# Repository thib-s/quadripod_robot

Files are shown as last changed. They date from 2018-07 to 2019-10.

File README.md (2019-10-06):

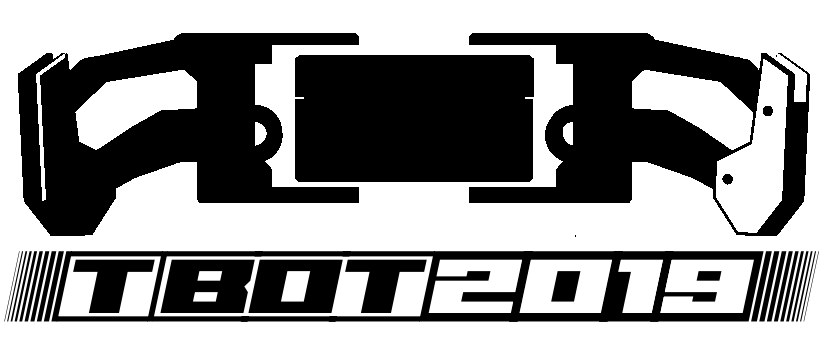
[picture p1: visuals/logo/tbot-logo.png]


Quadripod robot
===================

All the files to build a quadripod, including 3d model, eagle files and ROS code.

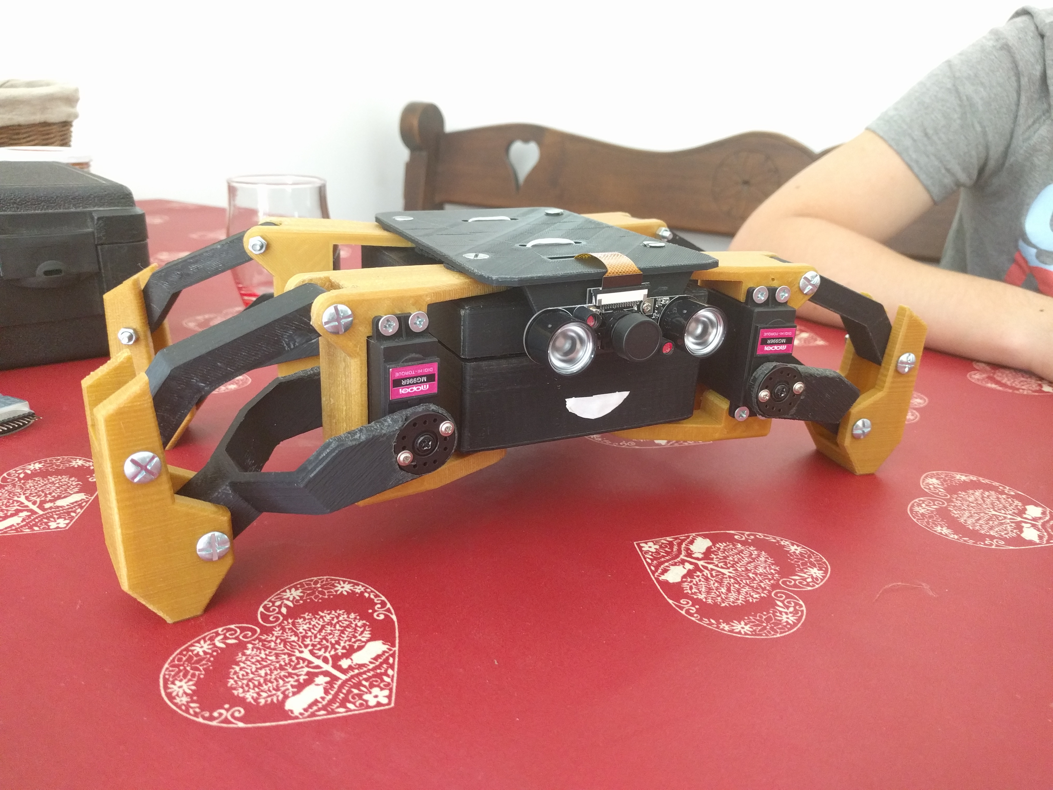
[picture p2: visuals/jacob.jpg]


Disclaimer
==========

This is a personal project, this means that this quadripod was build in a single exemplary. It worked fine for me, but i cannot be held responsible if you fry somehing using my plans.

Repository organization
=======================

3D
--

Contains stl for 3d print the robot, there are the original files from hackaday: [https://hackaday.io/project/9334-kame-esp8266-based-quadruped]. It contains also the modified STL to build the same base with mg996 servos.

Quadripod\_board
-------------

Contains the eagle files for the pcb manufacturing.

Code
----

Contains the code that runs on the raspberry pi zero:
 - The folder `catkin\_ws` contains the node to run locally on the robot. 
 - The folder `camera\_calibration` contains the files to calibrate the camera. 
 - The folder `teleop\_ws contains` the nodes to control the robot remotely using a joystick.
 
ROSpbianZero
------------

Contains the tutorial to setup the raspberry pi zero:
 1. install raspbian lite
 2. compile and install ros kinetic (perception)
 3. setup the service to start a launchfile at boot
 4. setup the wifi AP

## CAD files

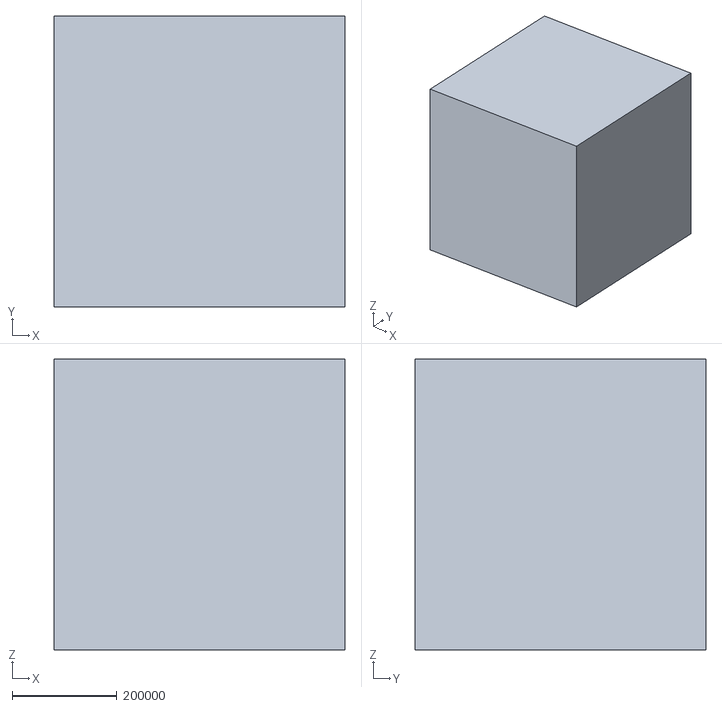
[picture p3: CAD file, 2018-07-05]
3d/mg996_base/exports/assembly.stl
554763.2 x 554763.2 x 554763.2

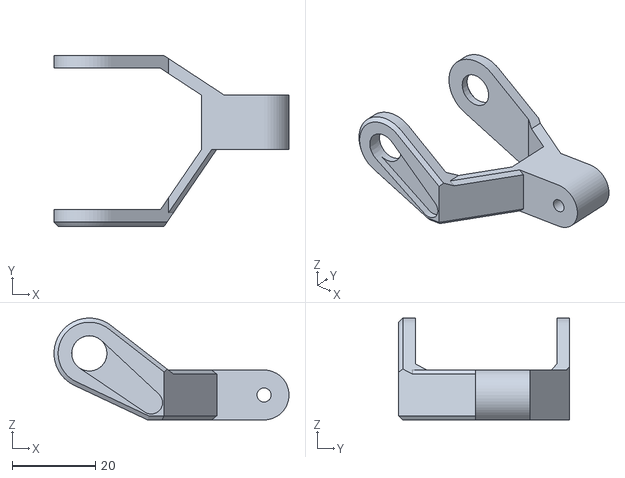
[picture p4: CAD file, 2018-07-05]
3d/hackaday_base/leftLegB.stl
56.5 x 41.0 x 24.5

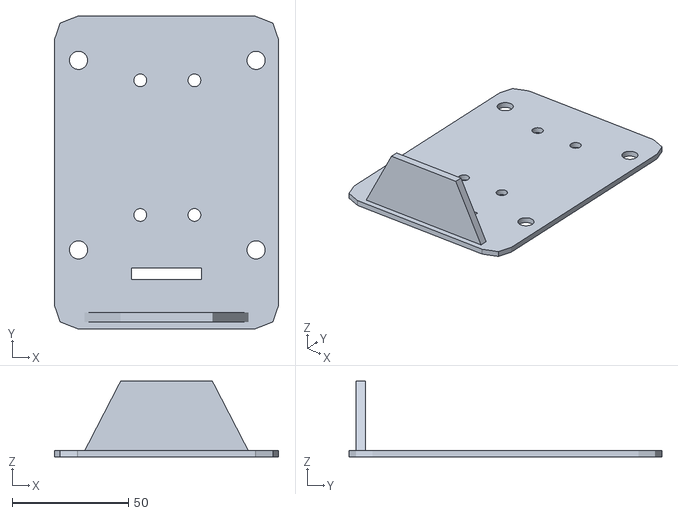
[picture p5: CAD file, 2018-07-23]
3d/mg996_base/exports/raspi_hat.stl
96.5 x 134.7 x 32.7

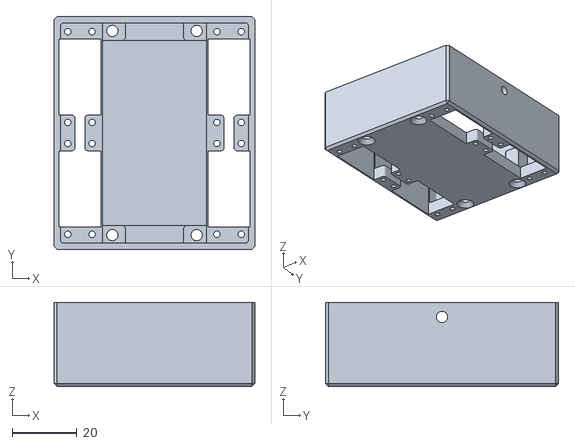
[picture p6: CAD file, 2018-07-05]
3d/hackaday_base/bodyB.stl
62.0 x 72.0 x 26.0

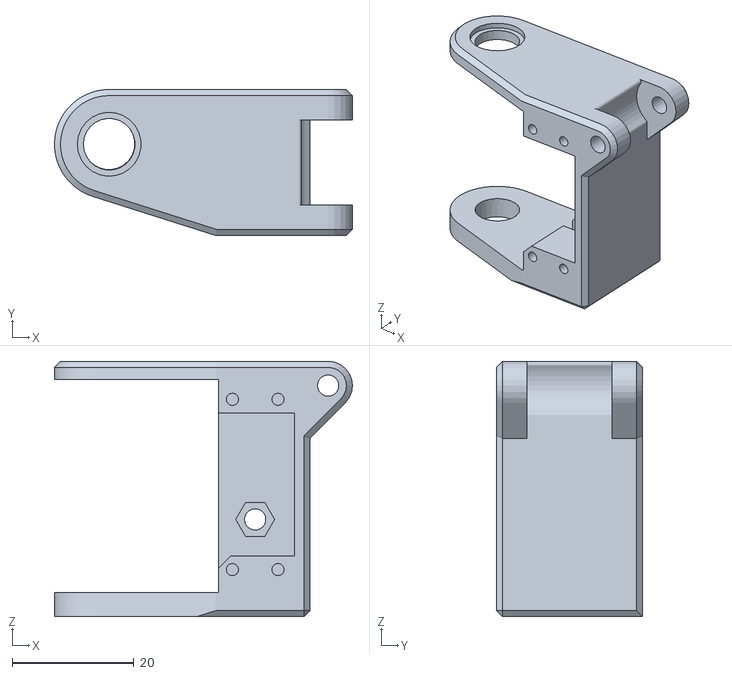
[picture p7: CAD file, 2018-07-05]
3d/mg996_base/leftBracket.stl
49.0 x 24.0 x 42.0

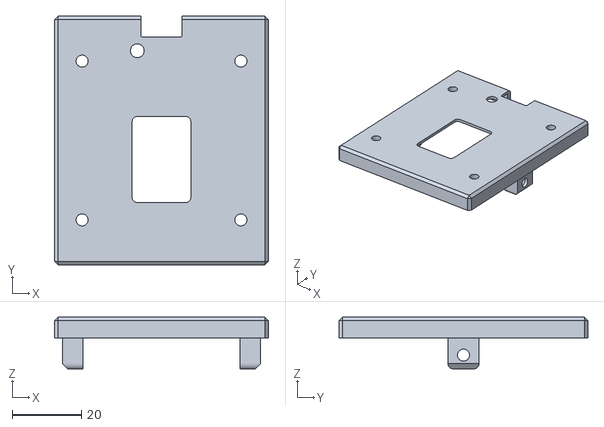
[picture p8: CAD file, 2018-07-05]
3d/mg996_base/bodyA.stl
62.0 x 72.0 x 15.0

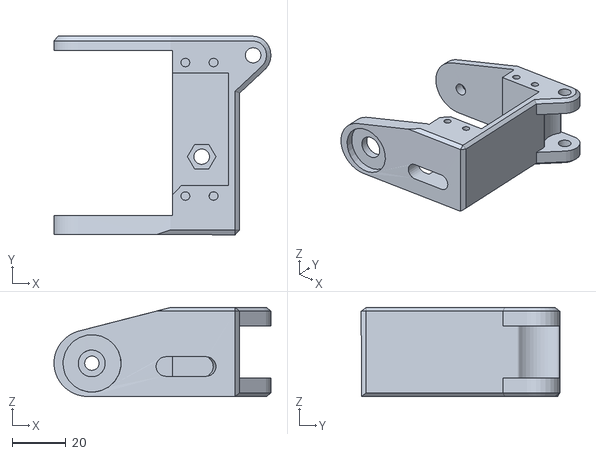
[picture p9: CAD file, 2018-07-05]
3d/mg996_base/exports/bracket.stl
80.6 x 73.7 x 33.0

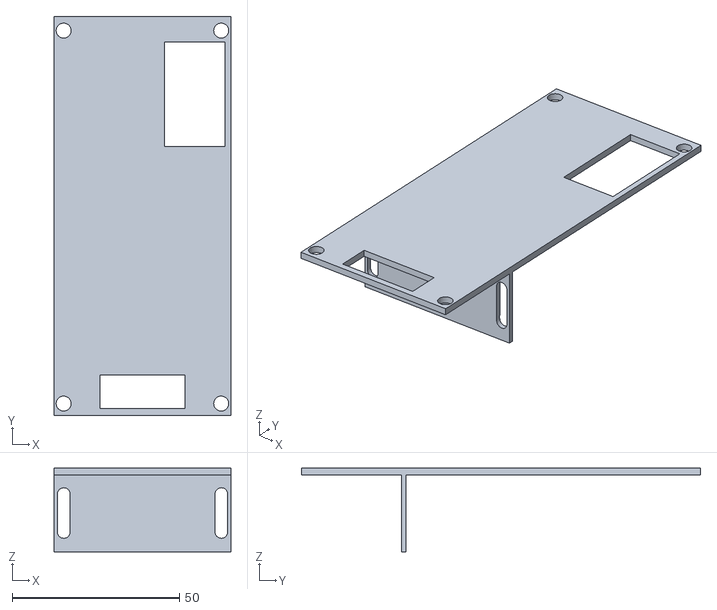
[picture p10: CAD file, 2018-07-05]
3d/mg996_base/exports/inner_body.stl
52.8 x 119.3 x 25.0

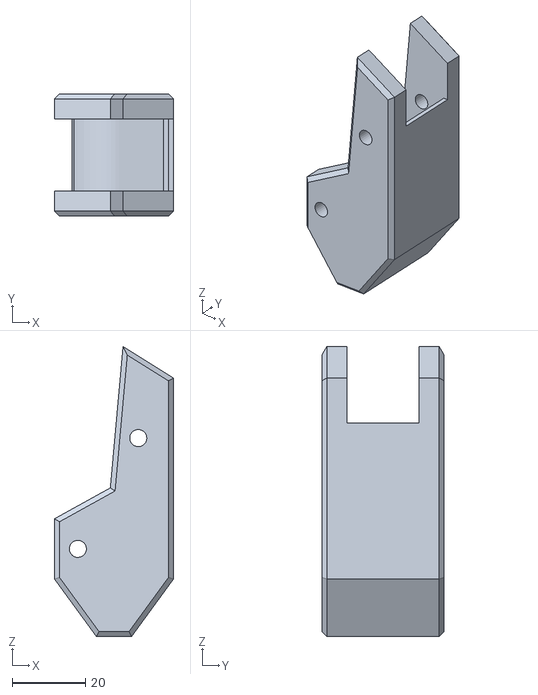
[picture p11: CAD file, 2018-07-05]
3d/mg996_base/exports/foot.stl
32.6 x 33.5 x 79.3

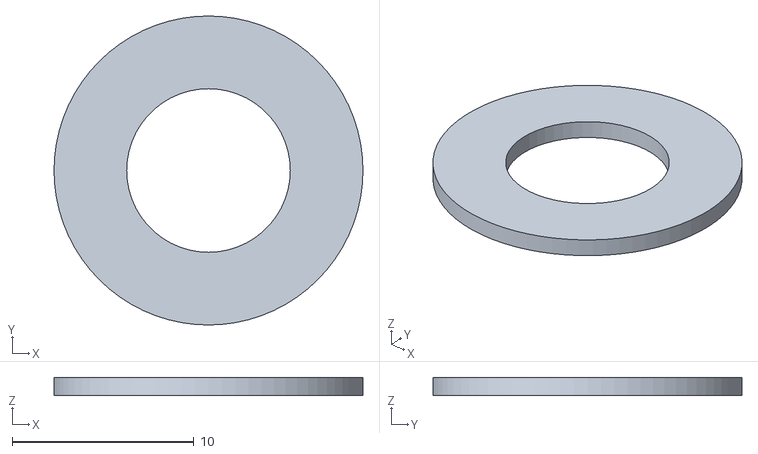
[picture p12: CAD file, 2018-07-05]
3d/hackaday_base/spacer.stl
17.0 x 17.0 x 1.00

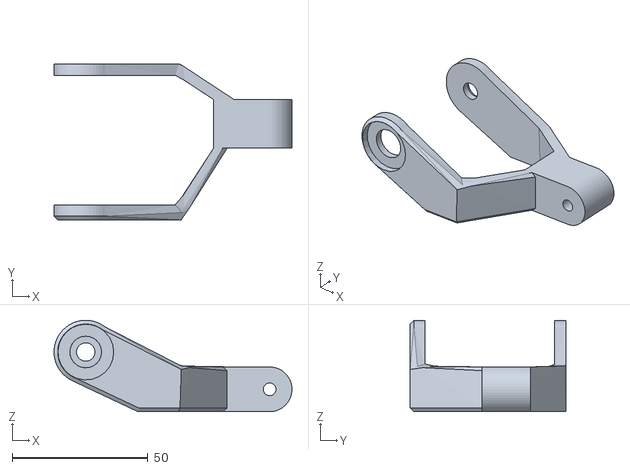
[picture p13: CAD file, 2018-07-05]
3d/mg996_base/exports/legB.stl
87.8 x 57.5 x 33.7

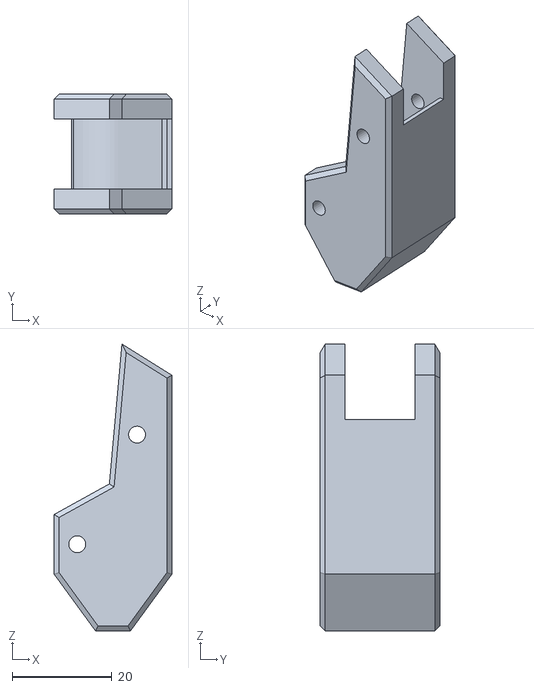
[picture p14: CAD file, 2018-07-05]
3d/hackaday_base/foot.stl
23.6 x 24.0 x 57.6

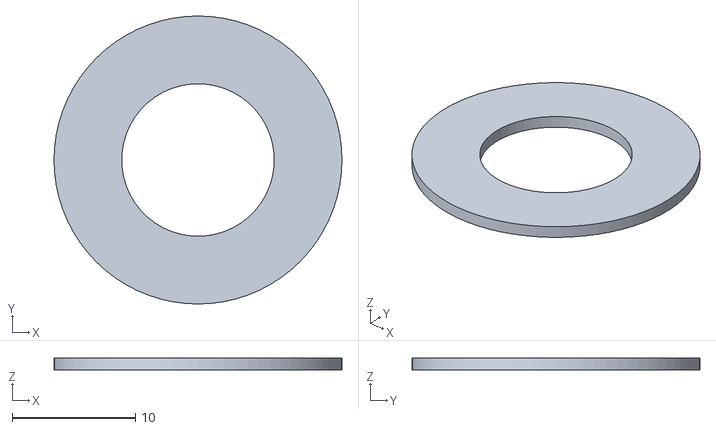
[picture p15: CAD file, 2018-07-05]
3d/mg996_base/exports/spacer.stl
23.4 x 23.4 x 1.00

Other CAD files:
3d/hackaday_base/rightBracket.stl
3d/hackaday_base/rightLegB.stl
3d/hackaday_base/legA.stl
3d/mg996_base/assembly.blend
3d/mg996_base/bodyA.blend
3d/mg996_base/bodyB.blend
3d/mg996_base/bracket.blend
3d/mg996_base/exports/bodyA.stl
3d/mg996_base/exports/bodyB.stl
3d/mg996_base/exports/legA.stl
3d/mg996_base/foot.blend
3d/mg996_base/inner_body.blend
3d/mg996_base/legA.blend
3d/mg996_base/legA.stl
3d/mg996_base/legB.blend
3d/mg996_base/raspi_hat.blend
3d/mg996_base/spacer.blend

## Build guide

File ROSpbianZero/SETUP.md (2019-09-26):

ROSpbianZero
============

This is a distribution is a modified RaspbianLite iso with ROS kinetic installed. This iso can also be configured to use the raspberry pi zero as a wifi hotspot.

The setup is split as follow:

1. raspbian stretch install
2. increase swap
3. ros compilation and install
4. wifi setup
5. setup to run nodes at boot
6. iso packing for further use

1: raspbian stretch install:
----------------------------

Go the [Raspbian website](https://www.raspberrypi.org/downloads/raspbian/) and download the the *Raspbian Lite* iso. Choose *raspbian jessie*.

Once done install it on a 16Go micro sd  ([tutorial](https://tutorials.ubuntu.com/tutorial/tutorial-create-a-usb-stick-on-ubuntu#0))

Log into the raspberry pi:
  login:pi
  pass:raspberry

change password and launch:
```
# sudo raspi-config
```
choose *expand filesystem*. You can also choose to enable ssh service (recommended). Enable camera and reboot.

Now install pigpio (usefull if you need the gpio! ):
```
# sudo apt-get update
# sudo apt-get install pigpio python-pigpio python3-pigpio
```

2: increase swap:
-----------------

Follow the [tutorial](https://wpitchoune.net/tricks/raspberry_pi3_increase_swap_size.html) and increase swap to 1024mb.

3: ROS install:
---------------

Add the repositories [step 1.2 - 1.3 of this tutorial](http://wiki.ros.org/kinetic/Installation/Ubuntu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)

Now follow the [tutorial](http://wiki.ros.org/kinetic/Installation/Source) to install ros kinetic from sources. **ATTENTION!!** read the entire paragraph before doing the tutorial, as some changes apply:

**edit 1**
in step 2.1.1 don't choose *desktop install* as we don't have any GUI. Choose *perception* instead. See also the [list of available variants](http://www.ros.org/reps/rep-0131.html#variants)
```
$ rosinstall\_generator robot perception --rosdistro kinetic --deps --wet-only --tar > kinetic-robot-perception-wet.rosinstall
$ wstool init -j8 src kinetic-robot-perception -wet.rosinstall
```

**edit 2**
Some package won't compile as is, you must apply the following patch:

```
-find_package(Eigen3 REQUIRED)
+find_package(PkgConfig)
+pkg_search_module(Eigen3 REQUIRED eigen3)
```  

Take a nap, the compile time is veeeeeerry long. You may also want to use *screen* or *byobu* to disconnet you ssh connection without stopping the compilation.

**Note:** Once the install is done and working you can delete the compilation folder. This will allow you to free up to 2Gb. (Usefull especially when packing the final iso).

4: wifi setup:
--------------

Follow [this tutorial](https://www.raspberrypi.org/documentation/configuration/wireless/access-point.md). The part *Using the Raspberry Pi as an access point to share an internet connection (bridge)* is optionnal.

5: setup ROS node at boot:
--------------------------

Create the file `/etc/systemd/system/bringup.service`:
```
[Unit]
Restart=on-abort
Description=ros\_bringup
After=network.target
  
[Service]
ExecStart=/bin/bash /usr/local/bin/bringup.sh

[Install]
WantedBy=default.target
```
This file will allow run `/usr/local/bin/bringup.sh` at boot.

Create now `/usr/local/bin/bringup.sh`:
```
#!/usr/bin/env bash
bash -c "source /opt/ros/kinetic/setup.bash && source /home/pi/catkin\_ws/devel/setup.bash && export ROS\_HOSTNAME=192.168.4.1 && export ROS\_MASTER\_URI=http://192.168.4.1:11311 && roslaunch bringup\_package bringup.launch > /tmp/bringup.log"
```

This command line allow to:
 - source ros executable
 - source your workspace executables
 - export variables to allow remote  ROS hosts
 - launch a launchfile

You may want to change this in order to launch an other launchfile. Without modifications this file run `bringup.launch` in the `bringup_package`.

Now adjust the acces:
```
# chmod 744 /usr/local/bin/bringup.sh
```

Then enable the service:
```
# chmod 664 /etc/systemd/system/bringup.service
# systemctl daemon-reload
# systemctl enable bringup.service
Created symlink from /etc/systemd/system/default.target.wants/bringup.service to /etc/systemd/system/bringup.service.
```

And start the service:
```
systemctl start bringup.service
```

**Note 1:** you can check the service status using `systemctl status bringup.service`

**Note 2:** The console output will be redirected in `/tmp/bringup.log`, this file is deleted at each restart.

6: pack the iso file:
---------------------

 1. poweroff the raspberry pi
 2. connect the sd card to a linux computer (ubuntu used to make this tutorial)
 3. run the `Disks` app
 4. select your sd card
 5. go into the options (top right button) and choose *create disk image*. Choose an iso name.

The obtained file is the size of the card (16Go), you can shrink it to it's minimal size (4.5Go) using [this tutorial](https://softwarebakery.com/shrinking-images-on-linux).

7: you're done!
---------------

This tutorial is intended for the raspberry pi zero, but also works on other models.

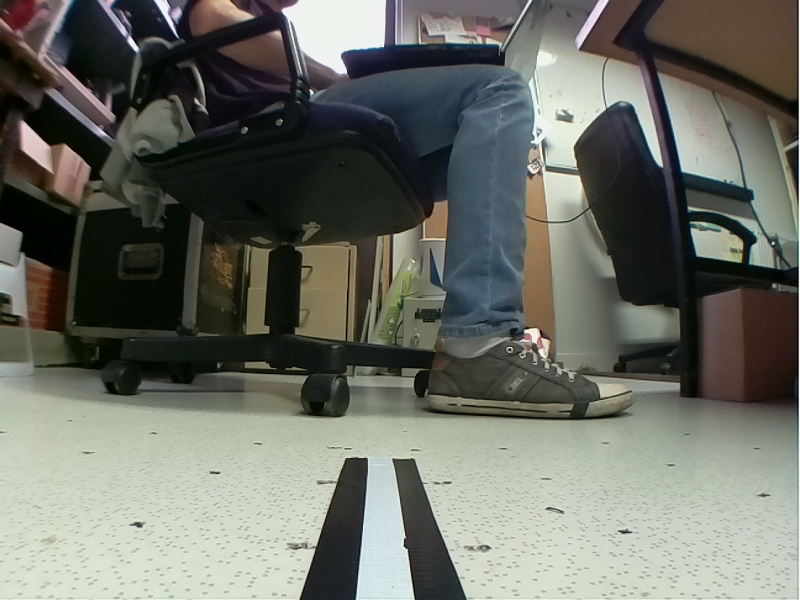
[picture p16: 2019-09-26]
code/camera_calibration/1step.png

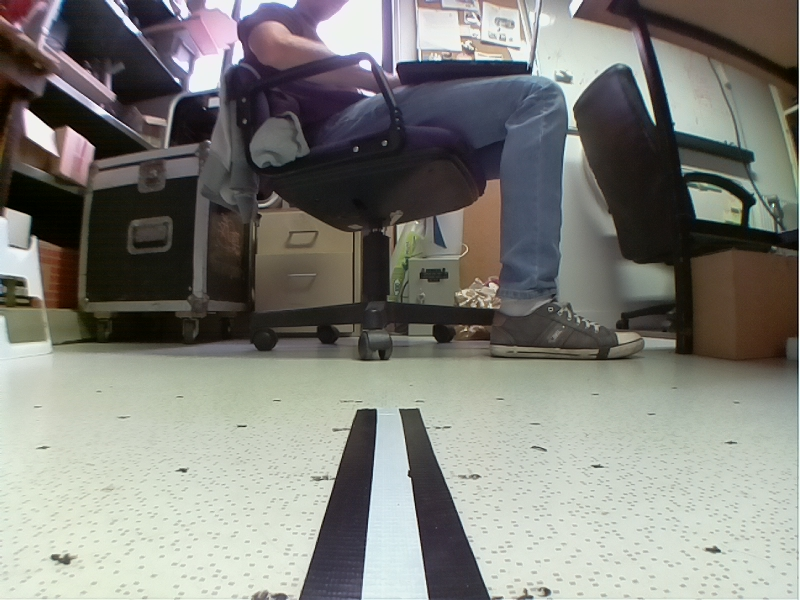
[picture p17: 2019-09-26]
code/camera_calibration/0step.png

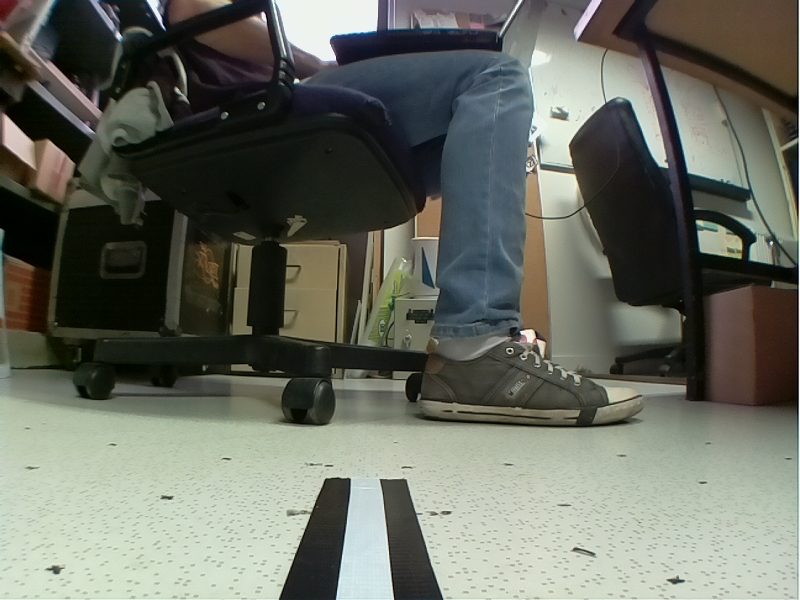
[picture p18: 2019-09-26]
code/camera_calibration/2step.png

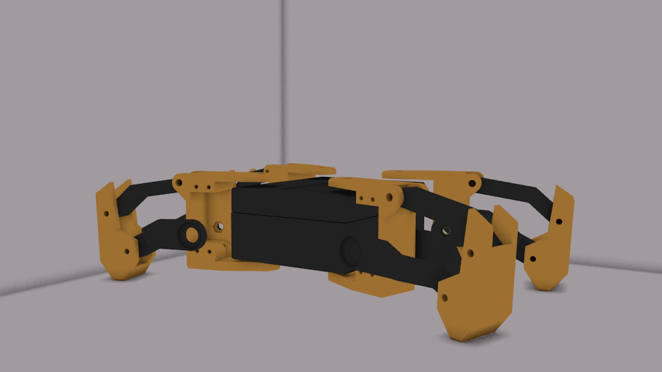
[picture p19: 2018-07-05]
3d/mg996_base/exports/assembly.png

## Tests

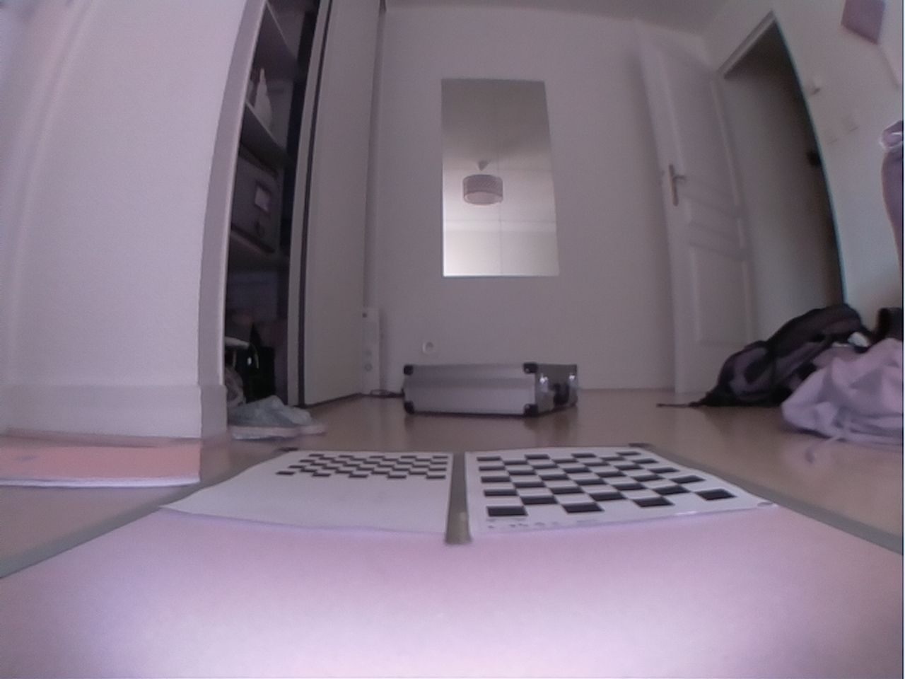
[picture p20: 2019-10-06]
code/camera_calibration/std.png

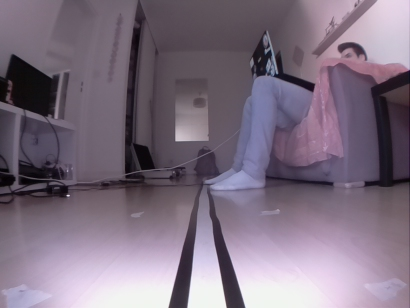
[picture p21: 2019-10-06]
code/camera_calibration/std_lowres.png

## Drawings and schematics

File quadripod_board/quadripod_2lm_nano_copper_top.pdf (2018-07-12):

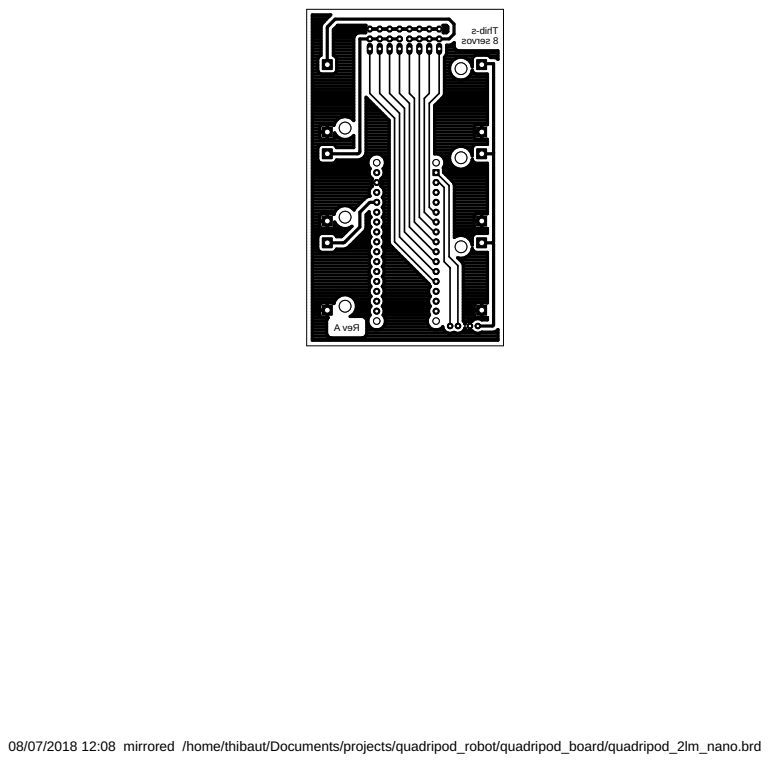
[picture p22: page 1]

08/07/2018 12:08 mirrored /home/thibaut/Documents/projects/quadripod_robot/quadripod_board/quadripod_2lm_nano.brd

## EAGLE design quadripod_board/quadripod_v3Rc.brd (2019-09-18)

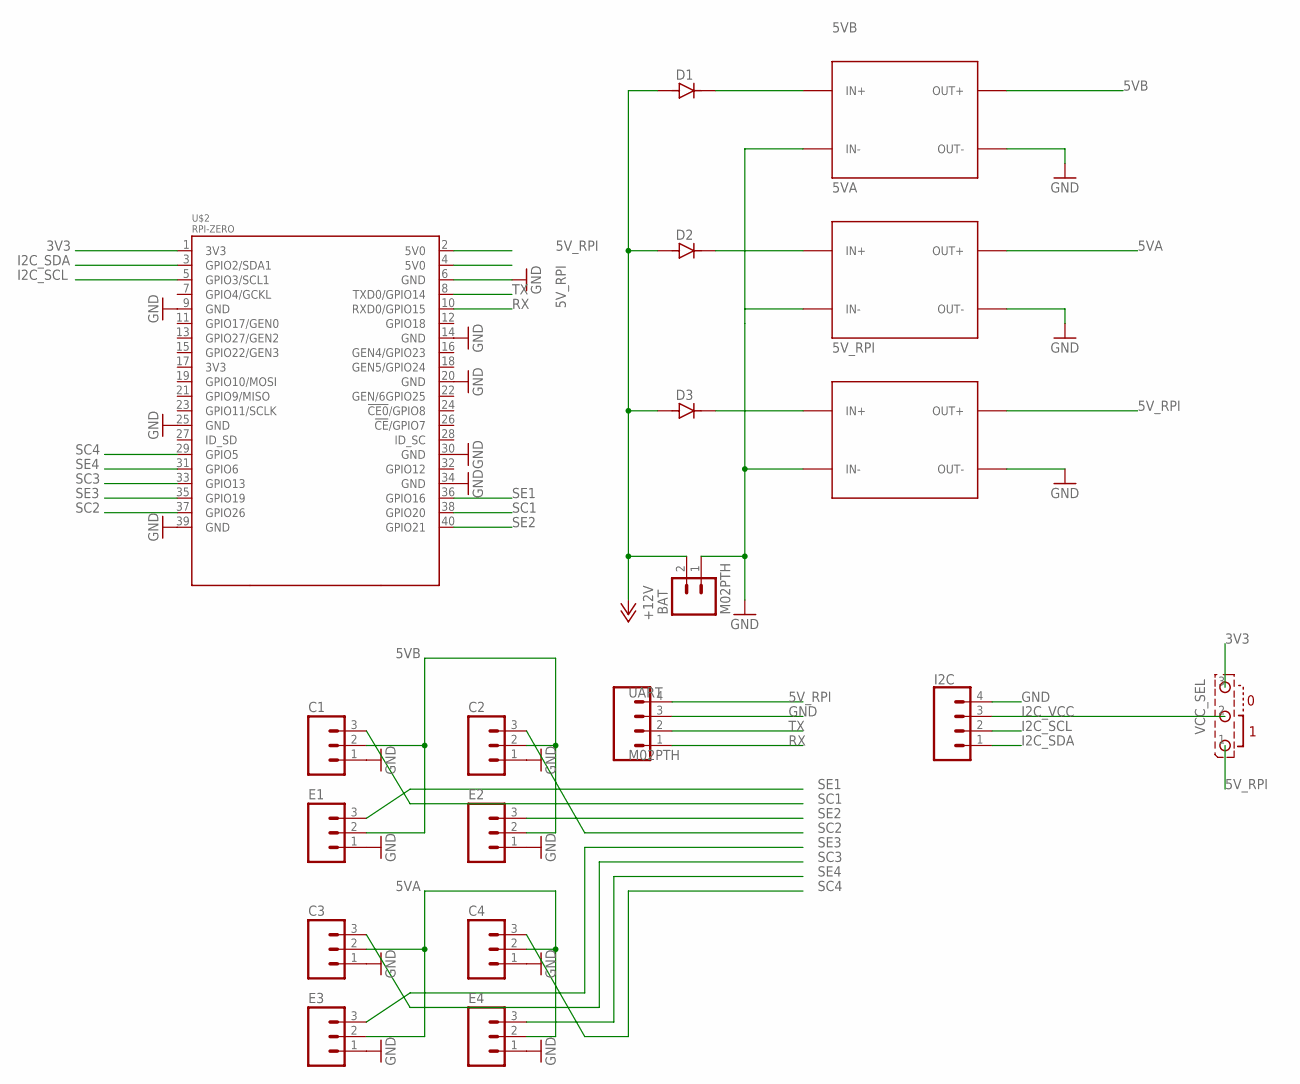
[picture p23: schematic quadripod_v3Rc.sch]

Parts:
5VA, 5VB, 5V_RPI: DC-DC-STEP-DOWN-LM2596
BAT: M02PTH; 1X02_LONGPADS
C1, C2, C3, C4: M03LONGPADS; 1X03_LONGPADS
D1, D2, D3: DIODES_DIODE/DO41; DIODES_DO41
E1, E2, E3, E4: M03LONGPADS; 1X03_LONGPADS
I2C: CONN_04LONGPADS; 1X04_LONGPADS
U$2: RPI-ZERO; RASPBERRYPI_BASTELSTUBE_V13_RASPI_BOARD_B+_FULL
UART: M02PTH; 1X04_LONGPADS
VCC_SEL: STCMS_3/CMS; STCMS_3

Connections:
3V3: U$2.1 (3V3), VCC_SEL.3
5VA: 5VA.OUT+, C3.2, C4.2, E3.2, E4.2
5VB: 5VB.OUT+, C1.2, C2.2, E1.2, E2.2
5V_RPI: 5V_RPI.OUT+, U$2.2 (5V0), U$2.4 (5V0), UART.4, VCC_SEL.1
+12V: BAT.2, D1.A, D2.A, D3.A
GND: 5VA.IN-, 5VA.OUT-, 5VB.IN-, 5VB.OUT-, 5V_RPI.IN-, 5V_RPI.OUT-, BAT.1, C1.1, C2.1, C3.1, C4.1, E1.1, E2.1, E3.1, E4.1, I2C.4, U$2.6 (GND), U$2.9 (GND), U$2.14 (GND), U$2.20 (GND), U$2.25 (GND), U$2.30 (GND), U$2.34 (GND), U$2.39 (GND), UART.3
I2C_SCL: I2C.2, U$2.5 (GPIO3/SCL1)
I2C_SDA: I2C.1, U$2.3 (GPIO2/SDA1)
I2C_VCC: I2C.3, VCC_SEL.2
unnamed: 5VB.IN+, D1.K
unnamed: 5V_RPI.IN+, D3.K
unnamed: 5VA.IN+, D2.K
RX: U$2.10 (RXD0/GPIO15), UART.1
SC1: C1.3, U$2.38 (GPIO20)
SC2: C2.3, U$2.37 (GPIO26)
SC3: C3.3, U$2.33 (GPIO13)
SC4: C4.3, U$2.29 (GPIO5)
SE1: E1.3, U$2.36 (GPIO16)
SE2: E2.3, U$2.40 (GPIO21)
SE3: E3.3, U$2.35 (GPIO19)
SE4: E4.3, U$2.31 (GPIO6)
TX: U$2.8 (TXD0/GPIO14), UART.2

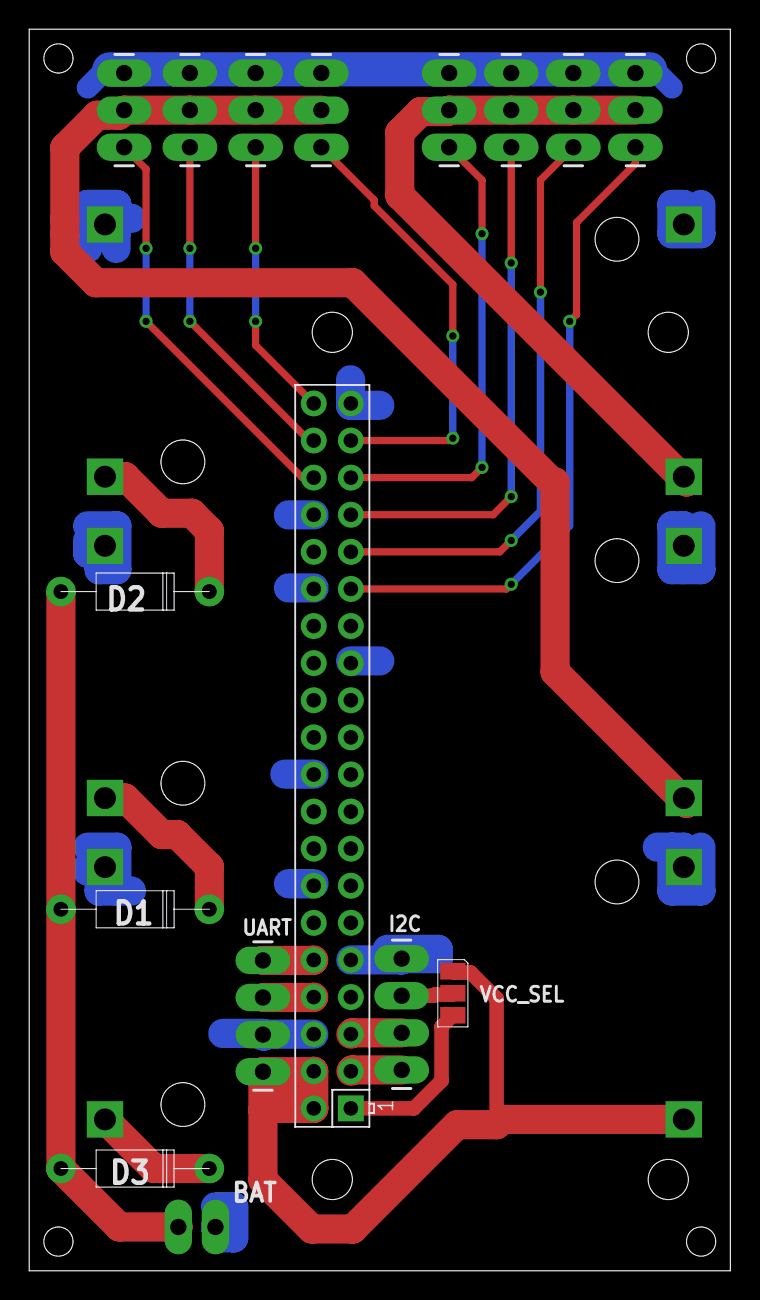
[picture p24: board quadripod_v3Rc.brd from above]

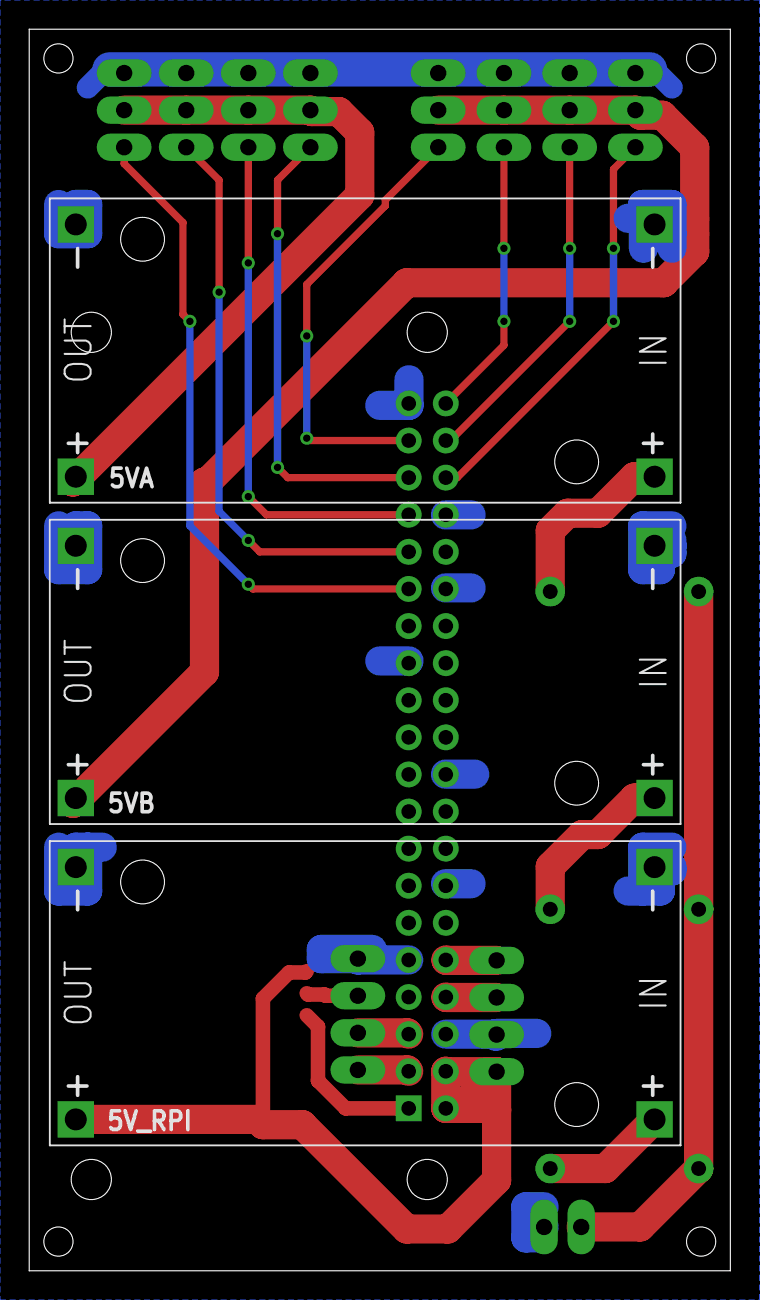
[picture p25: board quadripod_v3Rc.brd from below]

Board: 2 copper layers, 48.0 x 85.0 mm, 19 parts (4 on the bottom side), 22 nets.

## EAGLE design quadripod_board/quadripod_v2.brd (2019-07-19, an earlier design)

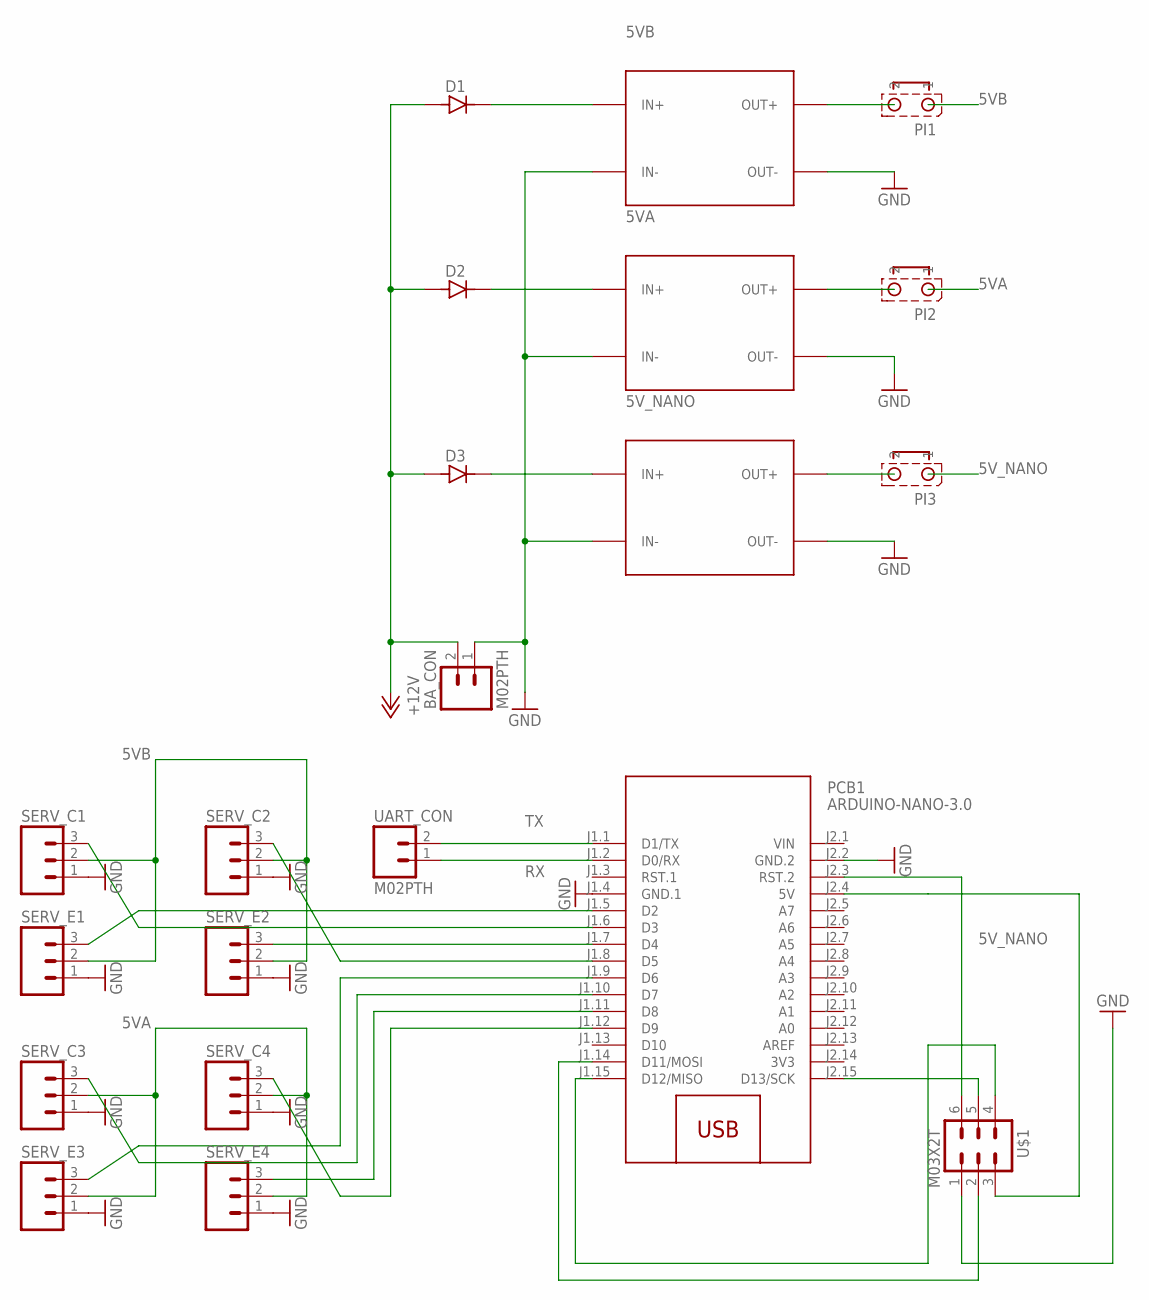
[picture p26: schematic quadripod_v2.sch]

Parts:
5VA, 5VB, 5V_NANO: DC-DC-STEP-DOWN-LM2596
BA_CON: M02PTH; 1X02
D1, D2, D3: DIODES_DIODE/DO41; DIODES_DO41
PCB1: ARDUINO-NANO-3.0
PI1, PI2, PI3: STCMS_2
SERV_C1, SERV_C2, SERV_C3, SERV_C4: M03LONGPADS; 1X03_LONGPADS
SERV_E1, SERV_E2, SERV_E3, SERV_E4: M03LONGPADS; 1X03_LONGPADS
U$1: M03X2T; 2X03
UART_CON: M02PTH; 1X02

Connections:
3V3: PCB1.J2.14 (3V3)
5VA: PI2.1, SERV_C3.2, SERV_C4.2, SERV_E3.2, SERV_E4.2
5VB: PI1.1, SERV_C1.2, SERV_C2.2, SERV_E1.2, SERV_E2.2
5V_NANO: PCB1.J2.4 (5V), PI3.1, U$1.3
+12V: BA_CON.2, D1.A, D2.A, D3.A
GND: 5VA.IN-, 5VA.OUT-, 5VB.IN-, 5VB.OUT-, 5V_NANO.IN-, 5V_NANO.OUT-, BA_CON.1, PCB1.J1.4 (GND.1), PCB1.J2.2 (GND.2), SERV_C1.1, SERV_C2.1, SERV_C3.1, SERV_C4.1, SERV_E1.1, SERV_E2.1, SERV_E3.1, SERV_E4.1, U$1.1
unnamed: 5VB.IN+, D1.K
unnamed: PCB1.J1.5 (D2), SERV_E1.3
unnamed: 5VA.IN+, D2.K
unnamed: 5V_NANO.IN+, D3.K
unnamed: PCB1.J1.6 (D3), SERV_C1.3
unnamed: PCB1.J1.7 (D4), SERV_E2.3
unnamed: PCB1.J1.8 (D5), SERV_C2.3
unnamed: PCB1.J1.9 (D6), SERV_E3.3
unnamed: PCB1.J1.10 (D7), SERV_C3.3
unnamed: PCB1.J1.11 (D8), SERV_E4.3
unnamed: PCB1.J1.12 (D9), SERV_C4.3
unnamed: 5VB.OUT+, PI1.2
unnamed: 5VA.OUT+, PI2.2
unnamed: 5V_NANO.OUT+, PI3.2
unnamed: PCB1.J1.14 (D11/MOSI), U$1.2
unnamed: PCB1.J2.3 (RST.2), U$1.6
unnamed: PCB1.J2.15 (D13/SCK), U$1.5
unnamed: PCB1.J1.15 (D12/MISO), U$1.4
RX: PCB1.J1.2 (D0/RX), UART_CON.1
TX: PCB1.J1.1 (D1/TX), UART_CON.2
VIN: PCB1.J2.1 (VIN)

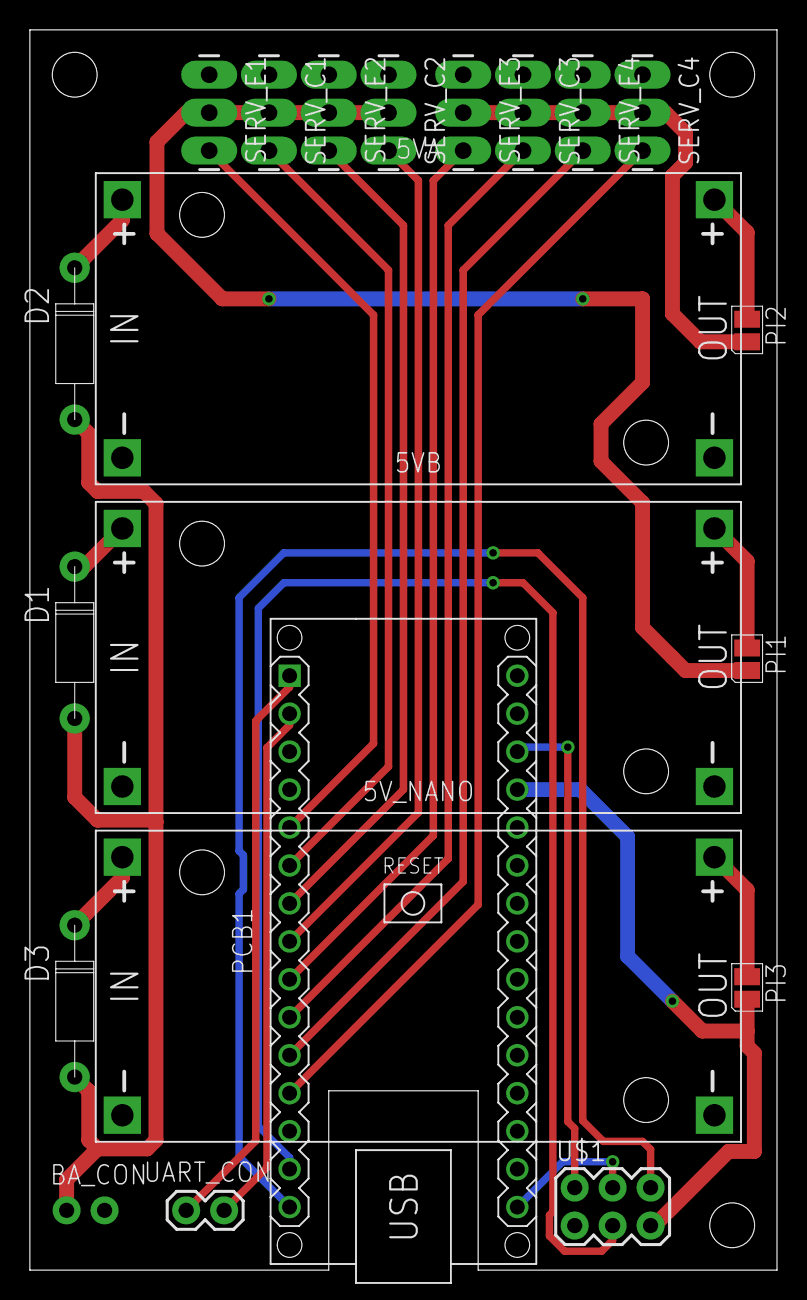
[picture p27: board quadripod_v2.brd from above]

Board: 2 copper layers, 50.0 x 83.0 mm, 21 parts (1 on the bottom side), 25 nets.

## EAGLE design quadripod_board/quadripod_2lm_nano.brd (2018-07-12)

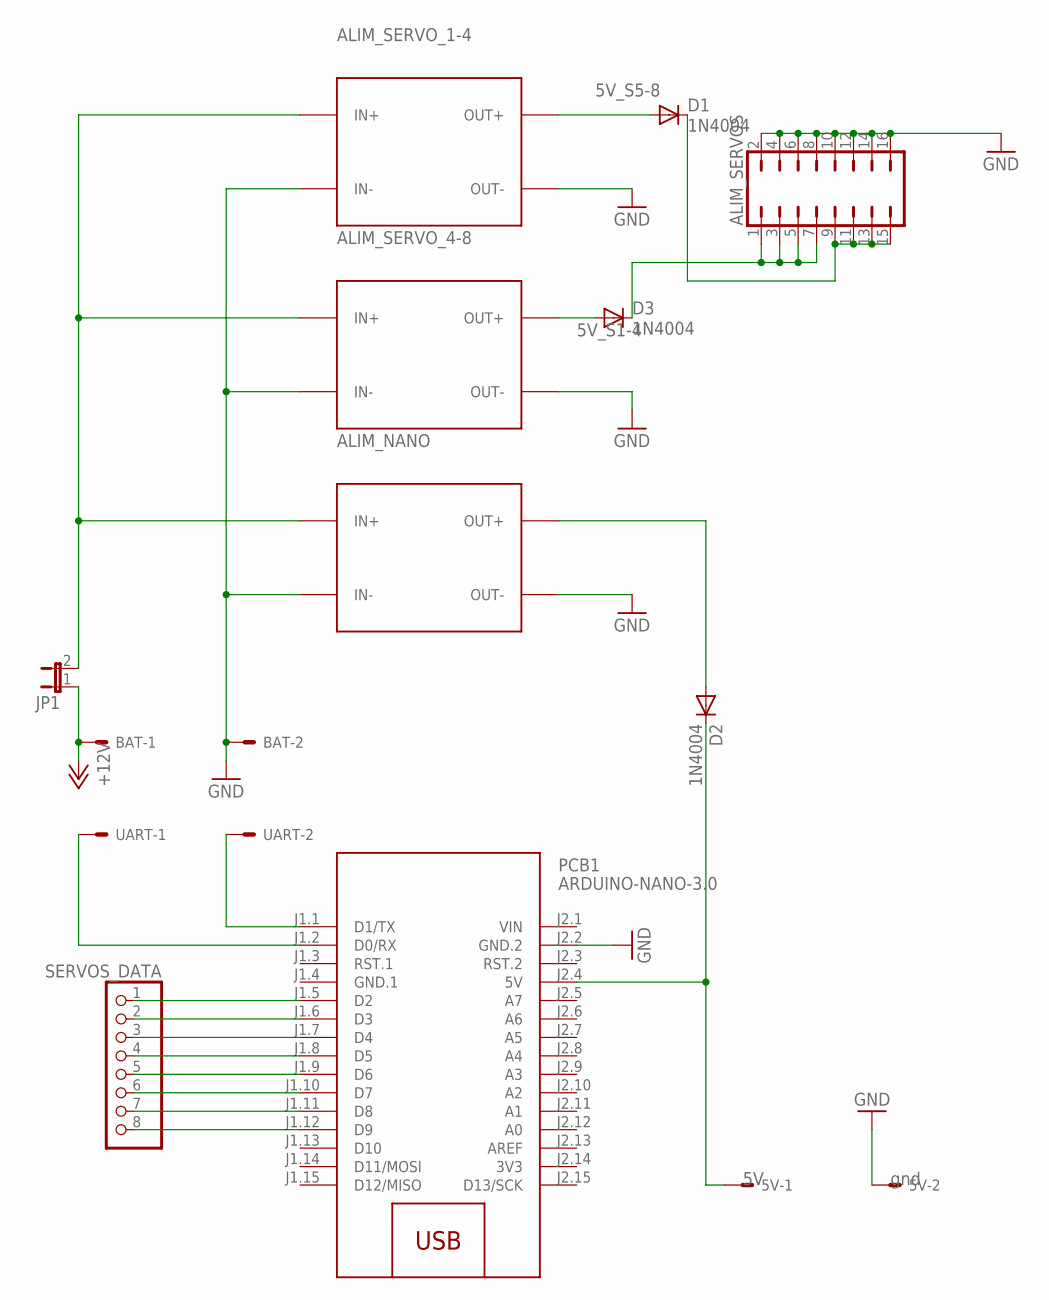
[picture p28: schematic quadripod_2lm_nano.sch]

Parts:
5V: 332-02
ALIM_NANO: DC-DC-STEP-DOWN-LM2596
ALIM_SERVOS: JP8Q
ALIM_SERVO_1-4, ALIM_SERVO_4-8: DC-DC-STEP-DOWN-LM2596
BAT: 332-02; VOLTAGE 12V
D1, D2, D3: 1N4004; DO41-10
JP1: JP1E; JP1
PCB1: ARDUINO-NANO-3.0
SERVOS_DATA: PINHD-1X8; 1X08
UART: 332-02

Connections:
3V3: PCB1.J2.14 (3V3)
5V_NANO: ALIM_NANO.OUT+, D2.A
5V_S1-4: ALIM_SERVOS.1, ALIM_SERVOS.3, ALIM_SERVOS.5, ALIM_SERVOS.7, D3.C
5V_S5-8: ALIM_SERVOS.9, ALIM_SERVOS.11, ALIM_SERVOS.13, ALIM_SERVOS.15, D1.C
+12V: BAT.1, JP1.1
GND: 5V.2, ALIM_NANO.IN-, ALIM_NANO.OUT-, ALIM_SERVOS.2, ALIM_SERVOS.4, ALIM_SERVOS.6, ALIM_SERVOS.8, ALIM_SERVOS.10, ALIM_SERVOS.12, ALIM_SERVOS.14, ALIM_SERVOS.16, ALIM_SERVO_1-4.IN-, ALIM_SERVO_1-4.OUT-, ALIM_SERVO_4-8.IN-, ALIM_SERVO_4-8.OUT-, BAT.2, PCB1.J2.2 (GND.2)
GND.1: PCB1.J1.4 (GND.1)
unnamed: ALIM_SERVO_4-8.OUT+, D3.A
unnamed: PCB1.J1.5 (D2), SERVOS_DATA.1
unnamed: 5V.1, D2.C, PCB1.J2.4 (5V)
unnamed: ALIM_SERVO_1-4.OUT+, D1.A
unnamed: PCB1.J1.6 (D3), SERVOS_DATA.2
unnamed: PCB1.J1.7 (D4), SERVOS_DATA.3
unnamed: PCB1.J1.8 (D5), SERVOS_DATA.4
unnamed: PCB1.J1.9 (D6), SERVOS_DATA.5
unnamed: PCB1.J1.10 (D7), SERVOS_DATA.6
unnamed: PCB1.J1.11 (D8), SERVOS_DATA.7
unnamed: PCB1.J1.12 (D9), SERVOS_DATA.8
unnamed: PCB1.J1.2 (D0/RX), UART.1
unnamed: PCB1.J1.1 (D1/TX), UART.2
unnamed: ALIM_NANO.IN+, ALIM_SERVO_1-4.IN+, ALIM_SERVO_4-8.IN+, JP1.2
VIN: PCB1.J2.1 (VIN)

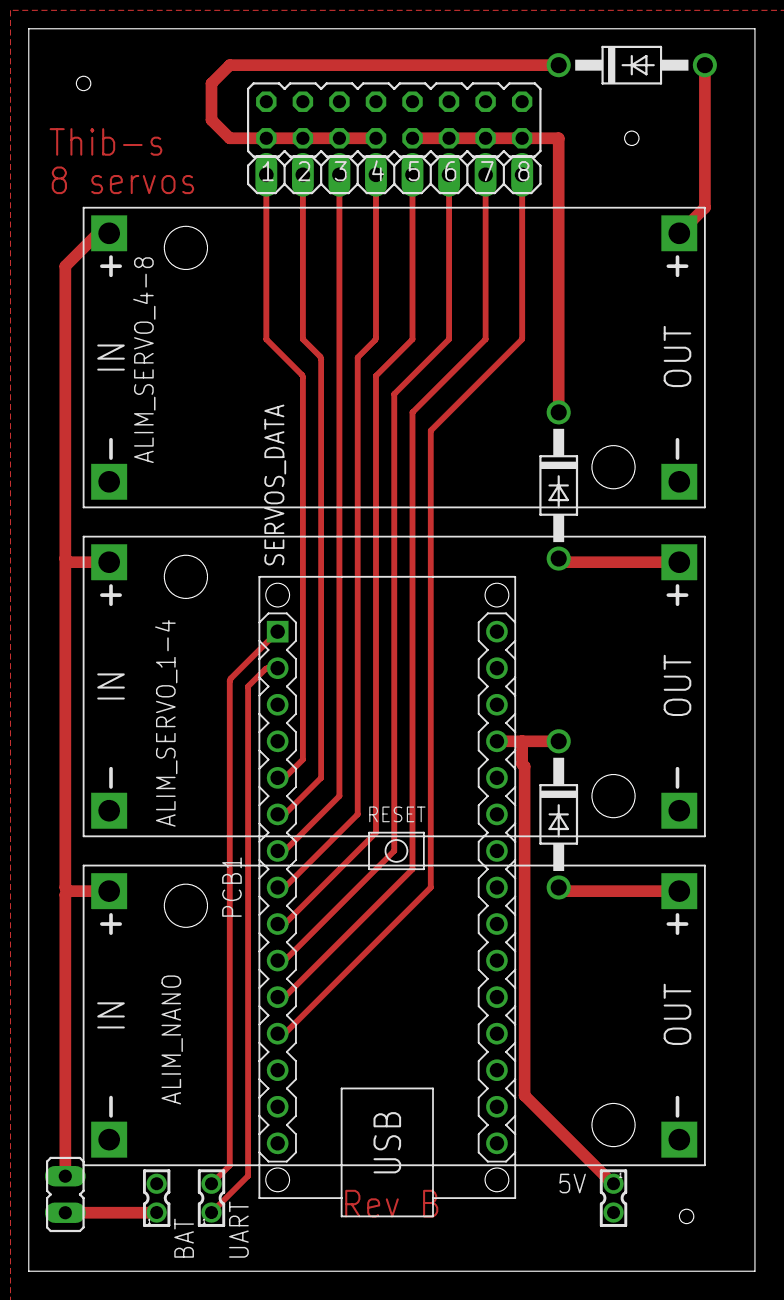
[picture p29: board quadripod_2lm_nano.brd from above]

Board: 2 copper layers, 50.5 x 86.4 mm, 13 parts (0 on the bottom side), 19 nets.

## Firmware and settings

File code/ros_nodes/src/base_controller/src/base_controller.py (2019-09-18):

#!/usr/bin/env python

# pulse.py

import rospy
from geometry_msgs.msg import Twist
import time
import numpy as np
import pigpio

deg2ms = lambda angle: (angle / 180.0) * 1000.0 + 1000.0


class ServoController():

    def __init__(self, pins=None):
        """
        Initialize the servo and move them to the standby position
        :return: nothing
        """
        if pins is None:
            # pins = [16, 20, 21, 26, 19, 13, 6, 5]
            # pins = [21, 26, 16, 20,6, 5, 19, 13]
            pins = [6,5,19,13,21,26,16,20]
        # gpio ids of each servo
        self.pins = pins

        self.pi = pigpio.pi()  # Connect to local Pi.

        # set gpio modes
        for pin in self.pins:
            self.pi.set_mode(pin, pigpio.OUTPUT)
        # start 1500 us servo pulses on gpio4
        for pin in self.pins:
            self.pi.set_servo_pulsewidth(pin, 1500)
            time.sleep(0.25)

    def move(self, position_sequence, correction, delay_step=0.25, delay_serv=0.0):
        for step in position_sequence:
            for i, pin in enumerate(self.pins):
                self.pi.set_servo_pulsewidth(pin, deg2ms(step[i] + correction[i]))
                time.sleep(delay_serv)
            time.sleep(delay_step)

    def release(self):
        """
        release all servos and stop the deamon
        :return:
        """
        for pin in self.pins:
            self.pi.set_servo_pulsewidth(pin, 0)  # stop servo pulses
        self.pi.stop()  # terminate connection and release resources


class QuadripodModel():

    def __init__(self,):

        ################################################
        # static params of the gait
        ################################################

        # how much to raise the legs when walking
        self.delta = 20

        self.init_angles = np.array(
            [[90, 90 + self.delta, 90, 90 - self.delta, 90, 90 - self.delta, 90, 90 + self.delta]])
        # values to correct mechanical alignment of servos
        self.corrections = np.array([-20, 10, 20, 0, 20, 20, -20, 0])

        # how to affect the values when moving the body without walking
        # body_p* refers to position
        # body_o* refers to orientation
        self.body_pz = np.array([0, 1, 0, -1, 0, -1, 0, 1])
        self.body_px = np.array([-1, 0, 1, 0, -1, 0, 1, 0])
        self.body_py = np.array([0, 0, 0, 0, 0, 0, 0, 0])  # None
        self.body_ox = np.array([0, -1, 0, -1, 0, 1, 0, 1])  # untested
        self.body_oy = np.array([0, 1, 0, -1, 0, 1, 0, -1])
        self.body_oz = np.array([0, 0, 0, 0, 0, 0, 0, 0])  # None

        self.body_twist = Twist()
        self.body_twist.linear.x = 0.
        self.body_twist.linear.y = 0.
        self.body_twist.linear.z = 0.
        self.body_twist.angular.x = 0.
        self.body_twist.angular.y = 0.
        self.body_twist.angular.z = 0.

    ################################################
    # functions that compute movement of the robot
    ################################################

    def walk(self, twist):
        """
        compute the legs position sequence in order to perform the walk
        :param twist: the twist msg with the movement infos: twist.linear.y for translation, and twist.angular.z for
        rotation
        :return: the sequence of the servos position as np array
        """
        linear = 0.5 * twist.linear.y + 0.5
        angular = 0.5 * twist.angular.z + 0.5
        linear_sequence = np.array([
            [75, 90, 70, 90 - self.delta, 110, 90 - self.delta, 105, 90],
            [75, 90 + self.delta, 70, 90, 110, 90, 105, 90 + self.delta],
            [110, 90 + self.delta, 110, 90, 75, 90, 60, 90 + self.delta],
            [110, 90, 110, 90 - self.delta, 75, 90 - self.delta, 60, 90]
        ])
        angular_sequence = np.array([
            [110, 90, 70, 90 - self.delta, 75, 90 - self.delta, 105, 90],
            [110, 90 + self.delta, 70, 90, 75, 90, 105, 90 + self.delta],
            [75, 90 + self.delta, 110, 90, 110, 90, 60, 90 + self.delta],
            [75, 90, 110, 90 - self.delta, 110, 90 - self.delta, 60, 90]
        ])
        return 0.5 * ((linear * linear_sequence) + (1 - linear) * linear_sequence[::-1]) \
               + 0.5 * ((angular * angular_sequence) + (1 - angular) * angular_sequence[::1])

    def compute_pose(self):
        """
        update the body pose by using the twist
        :param twist: the twist of the body pos refering to the legs
        :return: the correction to apply on the servos in order to achieve this body position
        """
        return self.corrections \
               + self.body_px * self.body_twist.linear.x \
               + self.body_py * self.body_twist.linear.y \
               + self.body_pz * self.body_twist.linear.z \
               + self.body_ox * self.body_twist.angular.x \
               + self.body_oy * self.body_twist.angular.y \
               + self.body_oz * self.body_twist.angular.z

    def set_body_twist(self, twist):
        """
        Set the body twist value
        :param twist: twist info about the body position/orientation
        :return: None
        """
        self.body_twist = twist


if __name__ == '__main__':
    rospy.init_node('base_controller', anonymous=False)
    controller = ServoController()
    quadripod = QuadripodModel()
    # move the legs to initial position
    controller.move(quadripod.init_angles, quadripod.corrections, 1., 1.)

    def move_callback(twist):
        if (abs(twist.linear.y) > 0.05) and (abs(twist.angular.z) > 0.05):
            walk_sequence = quadripod.walk(twist)
            body_pose = quadripod.compute_pose()
            # todo: replace controller.move by msg emission
            controller.move(walk_sequence, body_pose + quadripod.corrections)
        else:
            controller.move(quadripod.init_angles, quadripod.corrections)


    rospy.Subscriber("/cmd_vel", Twist, move_callback, queue_size=1)
    rospy.Subscriber("/body_pose", Twist, quadripod.set_body_twist, queue_size=1)
    # todo add rospy shutdown handler
    # rospy.spin()
    time.sleep(10)
    controller.release()

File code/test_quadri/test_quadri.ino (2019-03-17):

/**
   code permettant de tester la demarche du quadripode
   par Thibaut Boissin
   github: thib-s
*/
#include <Servo.h>

/* le tableau indexes permet de faire le lien entre
   l'id du servo <=> numero de la pin associée
   le id des servo sont donné de la manière suivante:
   1: epaule avnt droite
   2: coude avant droit
   3: epaule avant gauche
   4: coude avant gauche
   5: epaule arriere droite
   6: coude arriere droite
   7: epaule arriere gauche
   8: coude arriere gauche

   ici, nous avons: le coude avant droit (servo numero 1, dans la premiere case du tableau)
   associe a la pin 9 de l'arduino
*/
int indexes[] = { 9, 4, 7, 2, 5, 8, 3, 6};

Servo servos[8];  // tableau contenant les objet servos
// heureusement pour nous, un max de 8 objets servos peuvent etre crées

/*
   indique l'amplitude pour lever et baisser les pates
   la hauteur des pates etant definie comme position au repos +- delta
   pas besoin de trop essayer de comprendre ce bout, ca viendra en lisant le code
*/
static int delta = 20;

/*
   le temps de temporisation entre chaque étape de la démarche
*/
static int temporisation_time = 125;

/*
   le tableau init_angles indique quel angles doivent prendre chaque servo au debut du programm
   (position de repos). On le lit de la manière suivante:
   angle de l'epaule avant droite = 90 degrees (servo 1, associe a la premiere case du tableau,
   cf commentaire surle tableau indexes)
   angle du coude avant droite = 120 degrees (seconde case du tableau)
   etc...
*/
int init_angles[] = {90, 90 + delta, 90, 90 - delta, 90, 90 - delta, 90, 90 + delta};

/*
   ce tableau permet d'jouter un offset sur les servomoteurs, cela permet de corriger les
   erreurs d'assemblage, ici, par ex, l'epaule arriere droite (servo 5) etait trop en arriere,
   d'ou une correction de 20 degrees
*/
int correction[] = { -10, 15, 10, 0,  20, 0, -10, -15};

typedef bool (*funcptr)();

struct command{
  funcptr func;
  String signature;
};

/*
   TODO doc sur la comm
*/

extern bool move_general(float, float);
extern bool set_delta(int);
extern bool tilt_body(int);
extern bool raise_body(int);
extern bool say_hi();
extern bool display_error();


#define INT 1000
#define FLOAT 1001

command MOVE = { &move_general, "ff"};
command SET_DELTA = { &set_delta, "i"};
command TILT_BODY = { &tilt_body, "i"};
command RAISE_BODY = { &raise_body, "i"};
command SAY_HI = { &say_hi, ""};
command FAILED_PARSING = { &display_error, ""};

funcptr func;
int int_params[2];
float float_params[2];
String str_param = "command failed";

String input_string = "";         // a String to hold incoming data
boolean command_refreshed = false;  // whether the string is complete

static int tilt = 0;
static int height = 0;

/*
   au setup, on alloue les pin aux servos, et on donne au quadripod sa position initiale
*/
void setup()
{
  /*
     un petit delay a été mis au début, cela vient d'un soucis sur la revA de la carte
     sur la revA, il n'y a pas de diodes entre le 5V et l'étage d'alim, le 5v de l'arduino
     alimente donc indirectement les servos, et l'arduino se retrouve sous alimenté quand
     les servos bougent, rendant la reprogrammation impossible. Ce delay laisse donc un laps de temps
     pour pouvoir reflasher l'arduino (oui c'est très gitan, mais j'ai la flemme de graver un pcb pour
     la revB)
  */
  delay(5000);

  Serial.begin(1200);
  // reserve 200 bytes for the inputString:
  input_string.reserve(2000);
  // on alloue les pins, et on place les servos dans leurs positions initiales
  for (int i = 0; i < 8; i++) {
    servos[i].attach(indexes[i]);
    servos[i].write(init_angles[i] + correction[i]);
    // un petit delay est ajouté afin d'éviter que tous les servos bougent en même
    // temps, les alims, sont un peu limite pour l'usage qui en est fait ^^
    delay(temporisation_time);
  }
}

/*
   dans la loop on utilise a outrance la fonction move_general pour faire bouger le robot.
   Dans cetrte version, le robot fonctionne comme un automate ( pour l'instant )
   TODO: ajouter une lecture de commandes sur le serial pour pouvoir le piloter
*/
void loop()
{
  if (command_refreshed) {
    (*func)(); // call the function
    command_refreshed = false;
  } else {
//    Serial.println("doing nothing");
    perform_step(init_angles);
    delay(50);
  }
  /*
    if (Serial.find("set_delay(")) {
    int val = Serial.parseInt();
    Serial.print("set_delay(");
    Serial.print(val, DEC);
    Serial.println(")");
    }*/
}

/*
   fonction qui permet de faire un deplacement
   on lui donne deux paramêtres:
   float linear: vitesse lineaire du robot
                 c'est un valeur entre 0 et 1
                 a 0 on recule, et 1 on avance, 0.5, sur place
   float angular: vitesse angular du robot
                  valeur entre 0 et 1
                  a 0 rotation sens trigo, a 1 rotation sens horaire, a 0.5 pas de rotation
   il est bien sur possible de combiner les deux pour avancer en tournant!
   le robot est donc quasi holonome. ;)
*/
extern bool move_general() {
  /*
     comment ca marche la dedans ? on a une sequence de positions préenregistrées
     pour une marche en ligne droite dans la matrice suivante
     chaque colonne correspond a un servo, chaque ligne correspond à une étape de la marche
     on a donc un demarche en quatre etape:
     pour chaque pate:
        1. lever la pate
        2. avance la pate
        3. poser la pate
        4. reculer la pate

     la marche arrière est obtenue en jouant la sequence a l'envers
  */
  float linear = float_params[0];
  float angular = float_params[1];
  Serial.print("moving ");
  Serial.print(linear);
  Serial.print(",");
  Serial.println(angular);
  int angles_linear[4][8] = {
    {75,  90,       70, 90 - delta,  110, 90 - delta, 105, 90},
    {75,  90 + delta, 70, 90,        110, 90,       105, 90 + delta},
    {110, 90 + delta, 110, 90,       75,  90,       60,  90 + delta},
    {110, 90,       110, 90 - delta, 75,  90 - delta, 60,  90}
  };
  /*
     on fait de meme pour une demarche de rotation pure
      de la meme manière la rotation dans l'autre sens est obtenue en
      jouant la sequence a l"envers
  */
  int angles_angular[4][8] = {
    {110, 90,       70,  90 - delta,  75,  90 - delta, 105, 90},
    {110, 90 + delta, 70,  90,        75,  90,       105, 90 + delta},
    {75,  90 + delta, 110, 90,        110, 90,       60,  90 + delta},
    {75,  90,       110, 90 - delta,  110, 90 - delta, 60,  90}
  };
  // on joue sequentiellement chaque etape de la marche
  for (int act = 0; act < 4; act++) {
    // a chaque etape de la marche, on actualise tous les servos
    for (int serv = 0; serv < 8; serv++) {
      /*
         la demarche en ligne droite est calculé en combinant de manière pondérée les demarche de marche
         avant et de marche arrière, si linear vaut 0.5, le deux se compensent et le robot fait du sur place
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

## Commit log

2018-07-05 first commit, bien dodu on dirait
    [assembly.blend, assembly.stl, bodyA.blend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]
2018-07-12 board revision, added diodes to avoid powering the servos while programming the arduino
    [quadripod_2lm_nano.brd, quadripod_2lm_nano.sch]
2018-07-12 add correction system and values on servos test
    [test_servo.ino]
2018-07-12 fix des index, ajout des offset sur les servos, et de la doc!
    [test_quadri.ino]
2018-07-15 ajout de reglage d'amplitude pour la demarche + plein de fonctions pour regler les params dynamiquement
2018-07-23 3d model of camera + rpi holder
    [raspi_hat.blend, raspi_hat.stl]
2018-07-23 added uart interpreter
2018-10-27 slowed down the uart as pi zero use it for bt
2018-10-27 added disclamer, just in case
2019-07-19 update board, some checks to come
    [quadripod_v2.brd, quadripod_v2.sch, quadripod_v3.brd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]
2019-09-18 upate of the board
    [quadripod_v3Rc.brd, quadripod_v3Rc.sch]
2019-09-26 tutorial to install ROS on raspberry pi zero
2019-10-01 added line following and image calibration nodes
2019-10-03 use start button to disable manual control
2019-10-06 camera reprojection script
2019-11-03 fix bug in joystick button mapping

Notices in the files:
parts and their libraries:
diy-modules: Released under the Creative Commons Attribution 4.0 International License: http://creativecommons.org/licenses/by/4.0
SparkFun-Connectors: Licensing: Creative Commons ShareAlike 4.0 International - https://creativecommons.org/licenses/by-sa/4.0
